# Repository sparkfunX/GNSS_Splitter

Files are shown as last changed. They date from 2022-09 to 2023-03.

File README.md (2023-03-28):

# SparkX GNSS Antenna Splitter (Power Divider) with DC Pass

<p align="center">
  <a href="https://github.com/sparkfunX/GNSS_Splitter/issues" alt="Issues">
    </a>
  <a href="https://github.com/sparkfunX/GNSS_Splitter/actions" alt="Actions">
    </a>
  <a href="https://github.com/sparkfunX/GNSS_Splitter/blob/main/LICENSE.md" alt="License">
    </a>
  <a href="https://twitter.com/intent/follow?screen_name=sparkfun">
    </a>
</p>

SparkX GNSS Antenna Splitter (Power Divider) with DC Pass (https://www.sparkfun.com/products/21223)

*[SparkX GNSS Antenna Splitter (Power Divider) with DC Pass (SPX-21223)](https://www.sparkfun.com/products/21223)*

The [SparkX GNSS Antenna Splitter (Power Divider) with DC Pass (SPX-21223)](https://www.sparkfun.com/products/21223) lets you connect a single GNSS antenna to two boards or modules. It splits (divides) the antenna signal from Port S equally between Port 1 and Port 2. It is the perfect accessory for our [NEO-D9S correction data receiver](https://www.sparkfun.com/products/19390), allowing you to feed both the NEO-D9S and a separate GNSS module from a single antenna.

Our board is based on the BP2G1+ 2-way 50Ω DC Pass Power Splitter from Mini-Circuits. It covers the L-band frequencies from 1200 to 2000 MHz. The three ports are equipped with robust standard-polarity SMA sockets. We have an SMA Male-Male adapter available as an accessory should you want to change any or all sockets into plugs.

By default, the splitter will pass DC power from Port 1 to the antenna (Port S) so you can power your active antenna. However, it is easy to change this if required:

* By opening Jumper 1 and closing Jumper 2, you can provide DC power from Port 2 instead.
* With Jumper 1 open, you can also provide DC power from either the on-board Qwiic connector or via the VCC and GND breakout pads.
* With Jumper 1 open and both Qwiic and VCC disconnected, you can use our board as a passive 50:50 signal divider or combiner.

If your antenna needs 3.3V, Qwiic could be a good choice for you. The VCC and GND breakout pads will allow you to feed in a higher voltage (e.g. 5V) if required.

We have included a 10Ω current-limiting resistor for the Qwiic and VCC power connections, to help prevent damage if the antenna cable becomes shorted. If your antenna needs more than approx. 30mA, you can close the I<sub>lim</sub> jumper to bypass the resistor.

## Repository Contents

* **[/Documents](/Documents/)** - BP2G1+ datasheet
* **[/Hardware](/Hardware/)** - Eagle design files (.brd, .sch), Schematic, Board Dimensions

## Product Versions

* [SPX-21223](https://www.sparkfun.com/products/21223) - SparkX GNSS Antenna Splitter (Power Divider) with DC Pass - Initial SparkX Release

## License Information

This product is _**open source**_! 

Please review the LICENSE.md file for license information. 

If you have any questions or concerns on licensing, please contact technical support on our [SparkFun forums](https://forum.sparkfun.com/viewforum.php?f=152).

Distributed as-is; no warranty is given.

- Your friends at SparkFun.

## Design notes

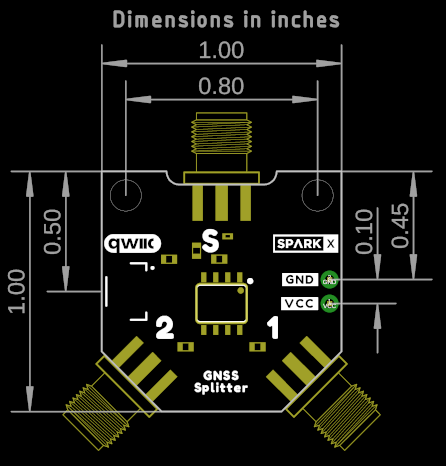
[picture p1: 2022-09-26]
Hardware/Dimensions.png

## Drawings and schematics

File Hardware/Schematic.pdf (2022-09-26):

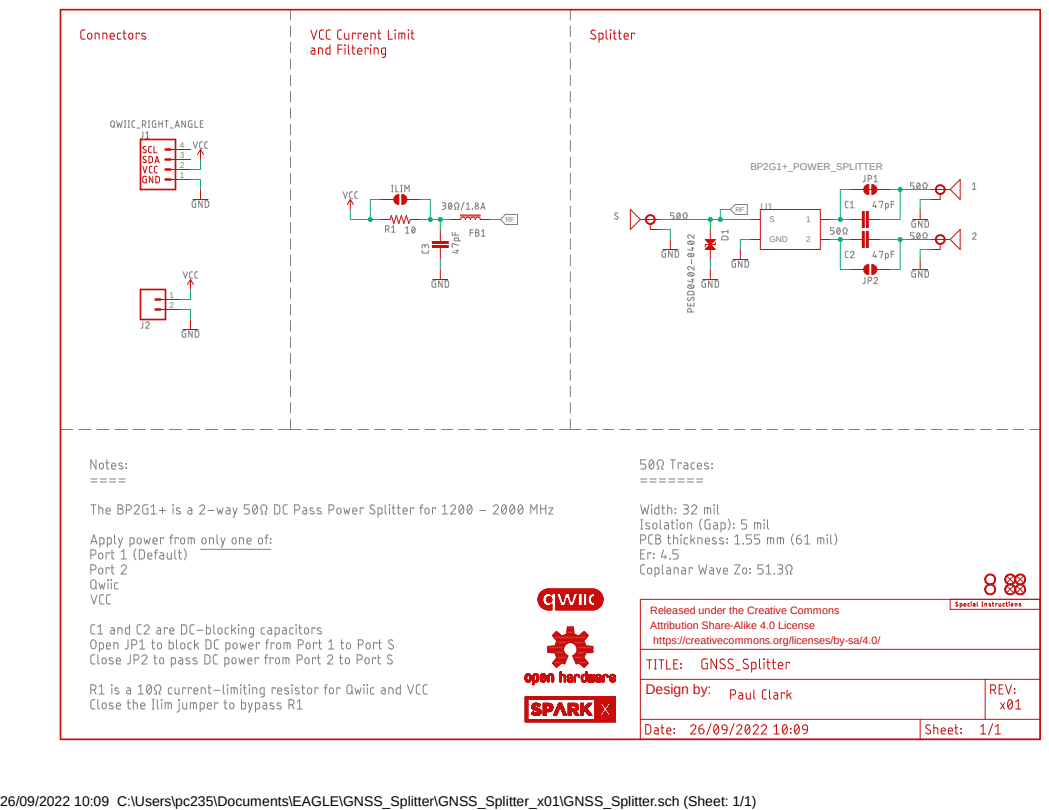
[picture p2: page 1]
BP2G1+_POWER_SPLITTER; 1 GND; Design by:

Released under the Creative Commons
Attribution Share-Alike 4.0 License
https://creativecommons.org/licenses/by-sa/4.0/

26/09/2022 10:09 C:\Users\pc235\Documents\EAGLE\GNSS_Splitter\GNSS_Splitter_x01\GNSS_Splitter.sch (Sheet: 1/1)

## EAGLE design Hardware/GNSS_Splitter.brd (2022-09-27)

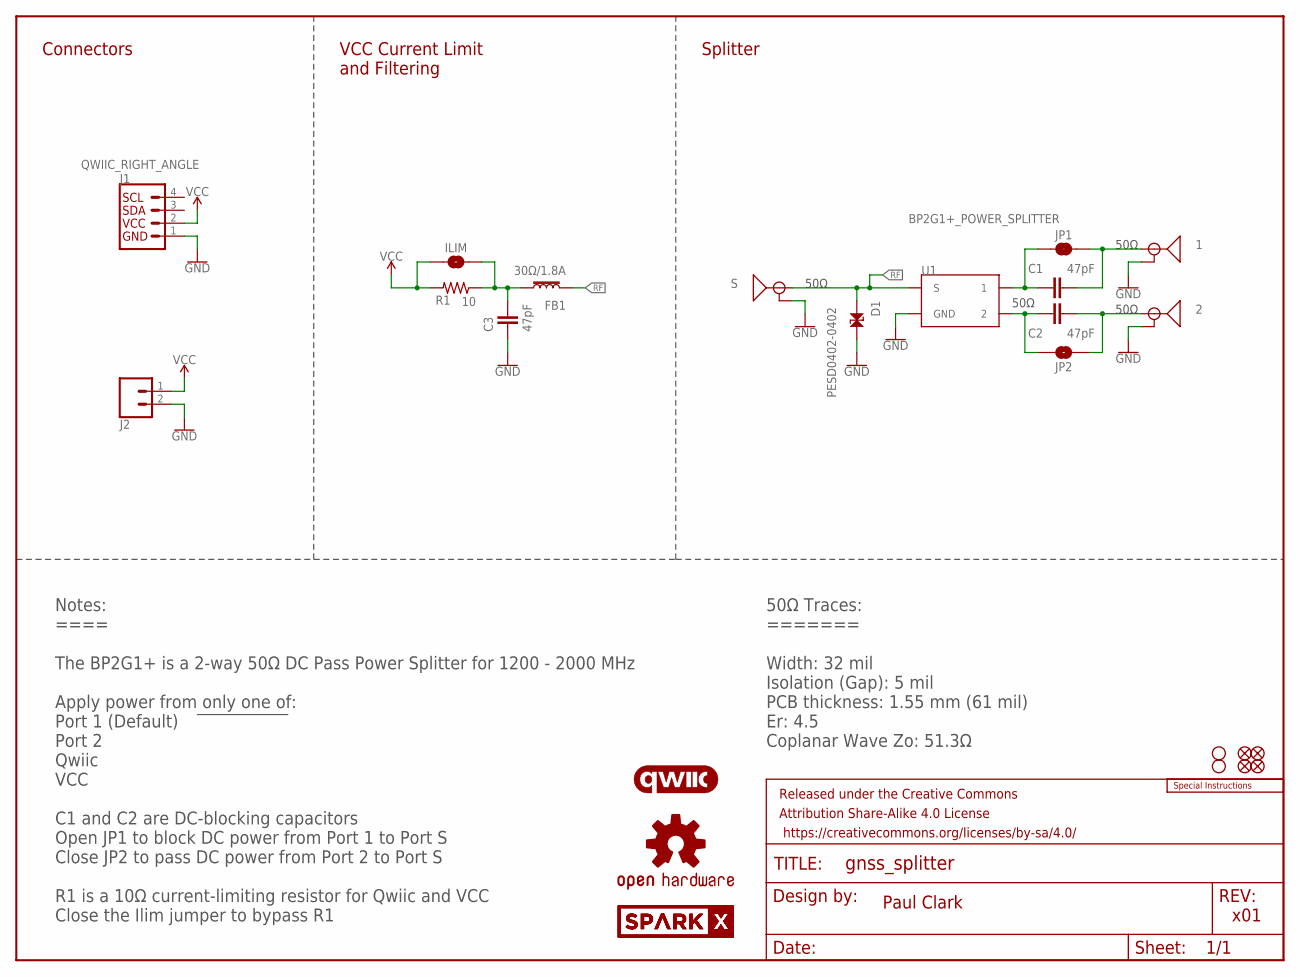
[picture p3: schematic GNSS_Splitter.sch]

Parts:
1, 2: ANTENNA-SMA-GROUNDEDEDGE_SMA; SMA-EDGE
C1, C2, C3: 47pF; 0603
D1: PESD0402-0402; 0402
FB1: 30Ω/1.8A; 0603
FD1, FD2, FD3, FD4: FIDUCIAL1X2; FIDUCIAL-1X2
FRAME1: FRAME-LETTER; CREATIVE_COMMONS
H1, H2: STAND-OFF
ILIM: JUMPER-SMT_2_NO_SILK; SMT-JUMPER_2_NO_SILK
J1: QWIIC_RIGHT_ANGLE; JST04_1MM_RA
J2: CONN_021X02_NO_SILK; 1X02_NO_SILK
JP1: JUMPER-SMT_2_NC_TRACE_SILK; SMT-JUMPER_2_NC_TRACE_SILK
JP2: JUMPER-SMT_2_NO_SILK; SMT-JUMPER_2_NO_SILK
LOGO1: OSHW-LOGOS; OSHW-LOGO-S
LOGO2: QWIIC_LOGO_6MM; QWIIC_6MM
LOGO3: SPECIAL_INSTRUCTIONS-ORDERING; ORDERING_INSTRUCTIONS
R1: 10; 0603
S: ANTENNA-SMA-GROUNDEDEDGE_SMA; SMA-EDGE
U1: BP2G1+_POWER_SPLITTER; XX21
U$1, U$2: SPARKX-LOGO3; SPARKX-SMALL

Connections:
GND: 1.GND@0 (GND), 1.GND@1 (GND), 1.GND@2 (GND), 1.GND@3 (GND), 2.GND@0 (GND), 2.GND@1 (GND), 2.GND@2 (GND), 2.GND@3 (GND), C3.1, D1.2, J1.1, J2.2, S.GND@0 (GND), S.GND@1 (GND), S.GND@2 (GND), S.GND@3 (GND), U1.1 (GND), U1.3 (GND), U1.4 (GND), U1.6 (GND), U1.7 (GND)
unnamed: C1.1, JP1.1, U1.8 (1)
unnamed: C3.2, FB1.1, ILIM.2, R1.1
unnamed: C2.2, JP2.2, U1.5 (2)
unnamed: 2.SIG (SIGNAL), C2.1, JP2.1
unnamed: 1.SIG (SIGNAL), C1.2, JP1.2
RF: D1.1, FB1.2, S.SIG (SIGNAL), U1.2 (S)
VCC: ILIM.1, J1.2, J2.1, R1.2

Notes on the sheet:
Paul Clark
x01
Notes: ==== The BP2G1+ is a 2-way 50Ω DC Pass Power Splitter for 1200 - 2000 MHz Apply power from only one of: Port 1 (Default) Port 2 Qwiic VCC C1 and C2 are DC-blocking capacitors Open JP1 to block DC power from Port 1 to Port S Close JP2 to pass DC power from Port 2 to Port S R1 is a 10Ω current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
50Ω
50Ω Traces: ======= Width: 32 mil Isolation (Gap): 5 mil PCB thickness: 1.55 mm (61 mil) Er: 4.5 Coplanar Wave Zo: 51.3Ω
Connectors
VCC Current Limit and Filtering
Splitter

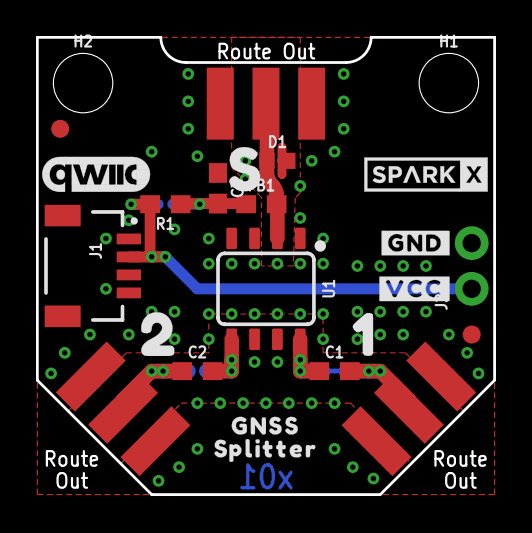
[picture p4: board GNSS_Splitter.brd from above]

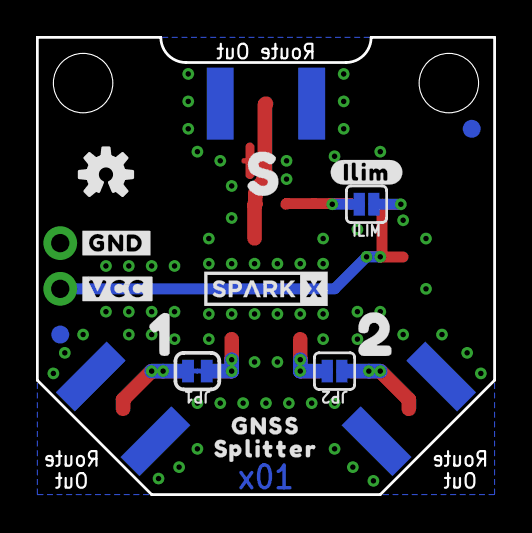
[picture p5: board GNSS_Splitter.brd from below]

Board: 2 copper layers, 25.4 x 25.4 mm, 44 parts (16 on the bottom side), 8 nets.

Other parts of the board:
U$3, U$7: 10
U$4, U$8: 20
U$5, U$6: S0
U$9: #GND#0
U$10: #GND#1
U$11: #VCC#0
U$12: #VCC#1
U$13, U$16: GNSS0
U$14, U$18: P0
U$15, U$17: S__LITTER0
U$19: #ILIM#0

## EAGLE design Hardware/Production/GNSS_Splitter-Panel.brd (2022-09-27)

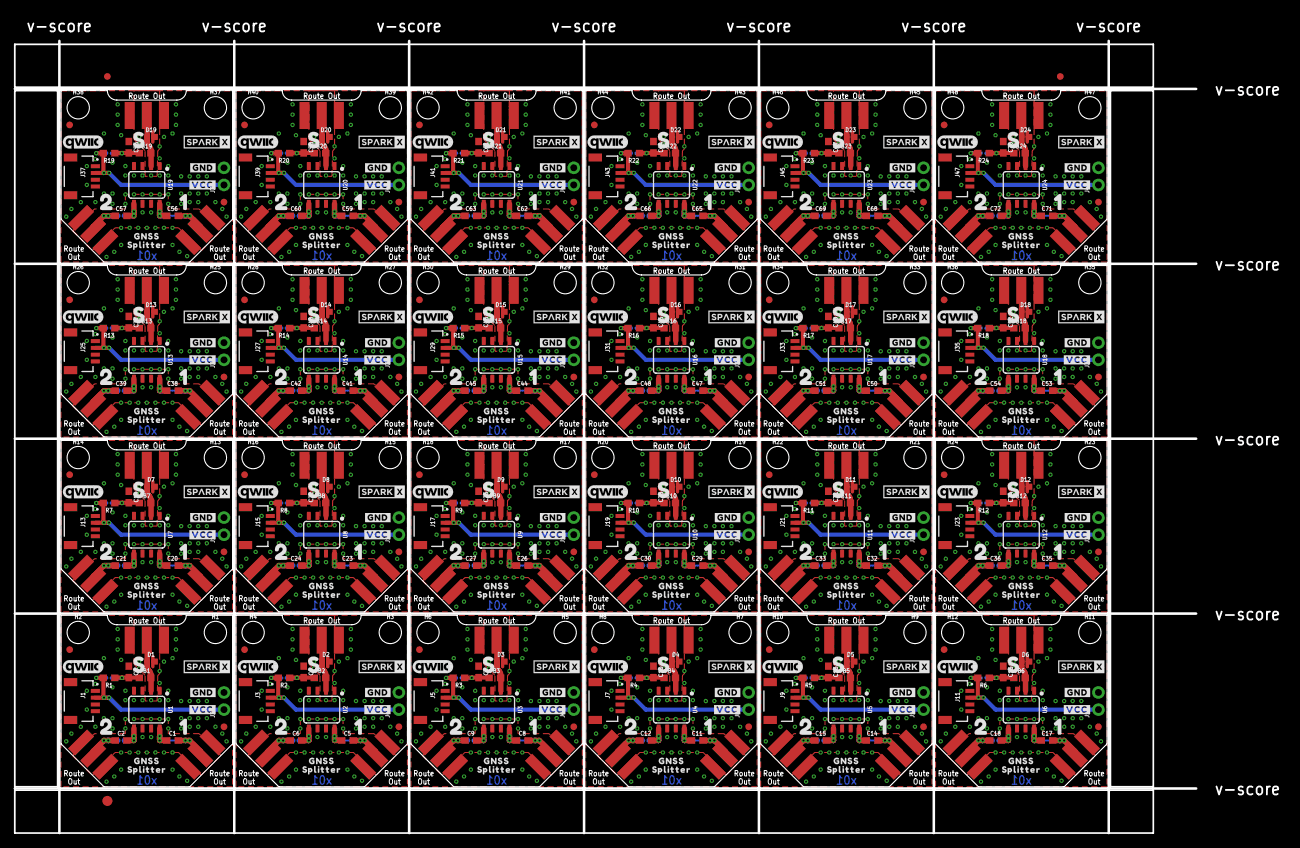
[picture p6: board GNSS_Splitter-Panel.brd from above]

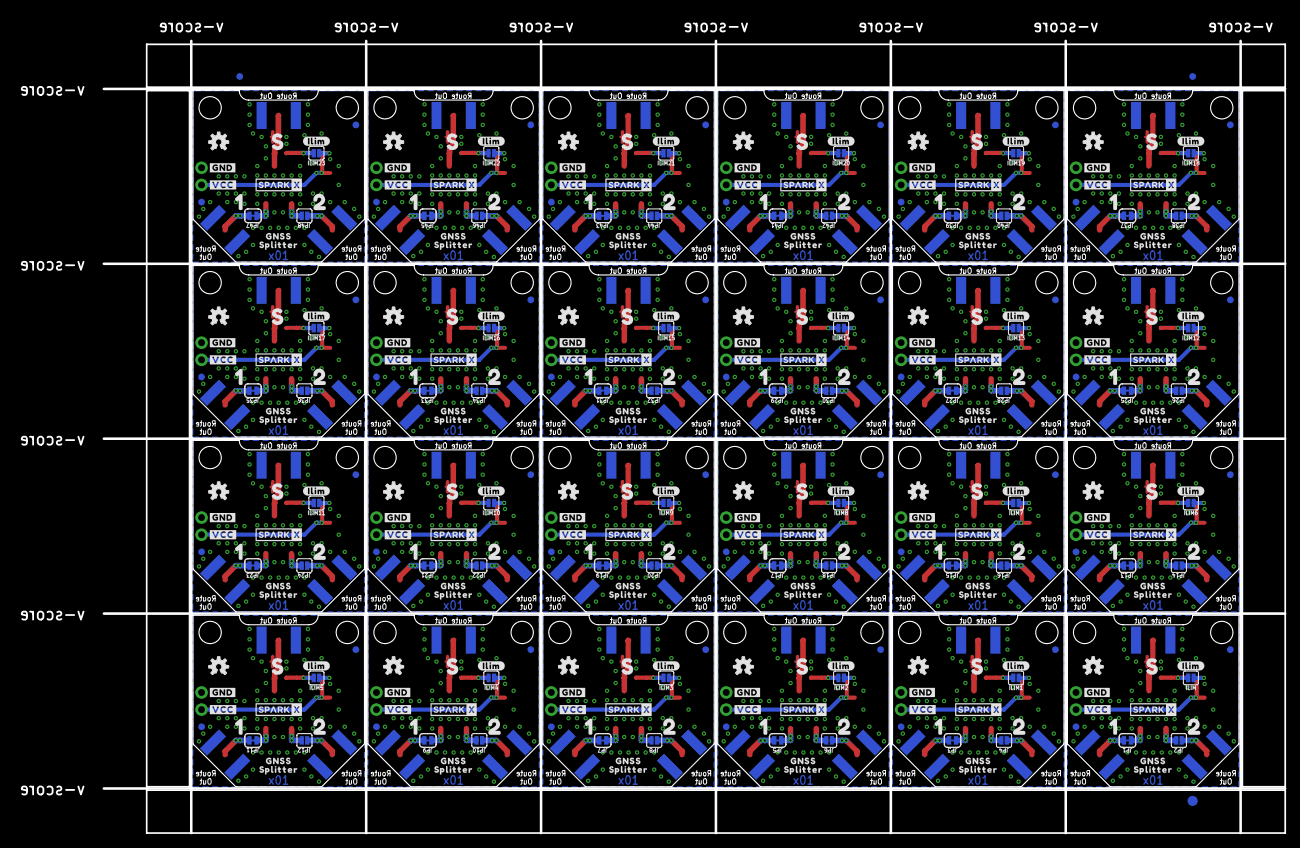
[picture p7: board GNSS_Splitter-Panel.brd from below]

Board: 2 copper layers, 175.0 x 117.3 mm, 1014 parts (387 on the bottom side), 192 nets.

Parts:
1, 2, 3, 4, 5, 6, 7, 8, 9, 10, 11, 12, 13, 14, 15, 16, 17, 18, 19, 20, 21, 22, 23, 24, 25, 26, 27, 28, 29, 30, 31, 32, 33, 34, 35, 36, 37, 38, 39, 40, 41, 42, 43, 44, 45, 46, 47, 48: ANTENNA-SMA-GROUNDEDEDGE_SMA; SMA-EDGE
C1, C2, C3, C4, C5, C6, C7, C8, C9, C10, C11, C12, C13, C14, C15, C16, C17, C18, C19, C20, C21, C22, C23, C24, C25, C26, C27, C28, C29, C30, C31, C32, C33, C34, C35, C36, C37, C38, C39, C40, C41, C42, C43, C44, C45, C46, C47, C48, C49, C50, C51, C52, C53, C54, C55, C56, C57, C58, C59, C60, C61, C62, C63, C64, C65, C66, C67, C68, C69, C70, C71, C72: 47pF; 0603
D1, D2, D3, D4, D5, D6, D7, D8, D9, D10, D11, D12, D13, D14, D15, D16, D17, D18, D19, D20, D21, D22, D23, D24: PESD0402-0402; 0402
E$1, E$2, E$3, E$4: FIDUCIAL-1X2
E$5, E$6: FIDUCIAL-1.5X3
FB1, FB2, FB3, FB4, FB5, FB6, FB7, FB8, FB9, FB10, FB11, FB12, FB13, FB14, FB15, FB16, FB17, FB18, FB19, FB20, FB21, FB22, FB23, FB24: 30Ω/1.8A; 0603
FD1, FD2, FD3, FD4, FD5, FD6, FD7, FD8, FD9, FD10, FD11, FD12, FD13, FD14, FD15, FD16, FD17, FD18, FD19, FD20, FD21, FD22, FD23, FD24, FD25, FD26, FD27, FD28, FD29, FD30, FD31, FD32, FD33, FD34, FD35, FD36, FD37, FD38, FD39, FD40, FD41, FD42, FD43, FD44, FD45, FD46, FD47, FD48, FD49, FD50, FD51, FD52, FD53, FD54, FD55, FD56, FD57, FD58, FD59, FD60, FD61, FD62, FD63, FD64, FD65, FD66, FD67, FD68, FD69, FD70, FD71, FD72, FD73, FD74, FD75, FD76, FD77, FD78, FD79, FD80, FD81, FD82, FD83, FD84, FD85, FD86, FD87, FD88, FD89, FD90, FD91, FD92, FD93, FD94, FD95, FD96: FIDUCIAL1X2; FIDUCIAL-1X2
H1, H2, H3, H4, H5, H6, H7, H8, H9, H10, H11, H12, H13, H14, H15, H16, H17, H18, H19, H20, H21, H22, H23, H24, H25, H26, H27, H28, H29, H30, H31, H32, H33, H34, H35, H36, H37, H38, H39, H40, H41, H42, H43, H44, H45, H46, H47, H48: STAND-OFF
ILIM, ILIM1, ILIM2, ILIM3, ILIM4, ILIM5, ILIM6, ILIM7, ILIM8, ILIM9, ILIM10, ILIM11, ILIM12, ILIM13, ILIM14, ILIM15, ILIM16, ILIM17, ILIM18, ILIM19, ILIM20, ILIM21, ILIM22, ILIM23: JUMPER-SMT_2_NO_SILK; SMT-JUMPER_2_NO_SILK
J1, J3, J5, J7, J9, J11, J13, J15, J17, J19, J21, J23, J25, J27, J29, J31, J33, J35, J37, J39, J41, J43, J45, J47: QWIIC_RIGHT_ANGLE; JST04_1MM_RA
J2, J4, J6, J8, J10, J12, J14, J16, J18, J20, J22, J24, J26, J28, J30, J32, J34, J36, J38, J40, J42, J44, J46, J48: 1X02_NO_SILK
JP1, JP3, JP5, JP7, JP9, JP11, JP13, JP15, JP17, JP19, JP21, JP23, JP25, JP27, JP29, JP31, JP33, JP35, JP37, JP39, JP41, JP43, JP45, JP47: JUMPER-SMT_2_NC_TRACE_SILK; SMT-JUMPER_2_NC_TRACE_SILK
JP2, JP4, JP6, JP8, JP10, JP12, JP14, JP16, JP18, JP20, JP22, JP24, JP26, JP28, JP30, JP32, JP34, JP36, JP38, JP40, JP42, JP44, JP46, JP48: JUMPER-SMT_2_NO_SILK; SMT-JUMPER_2_NO_SILK
LOGO1, LOGO3, LOGO5, LOGO7, LOGO9, LOGO11, LOGO13, LOGO15, LOGO17, LOGO19, LOGO21, LOGO23, LOGO25, LOGO27, LOGO29, LOGO31, LOGO33, LOGO35, LOGO37, LOGO39, LOGO41, LOGO43, LOGO45, LOGO47: OSHW-LOGOS; OSHW-LOGO-S
LOGO2, LOGO4, LOGO6, LOGO8, LOGO10, LOGO12, LOGO14, LOGO16, LOGO18, LOGO20, LOGO22, LOGO24, LOGO26, LOGO28, LOGO30, LOGO32, LOGO34, LOGO36, LOGO38, LOGO40, LOGO42, LOGO44, LOGO46, LOGO48: QWIIC_LOGO_6MM; QWIIC_6MM
R1, R2, R3, R4, R5, R6, R7, R8, R9, R10, R11, R12, R13, R14, R15, R16, R17, R18, R19, R20, R21, R22, R23, R24: 10; 0603
S, S1, S2, S3, S4, S5, S6, S7, S8, S9, S10, S11, S12, S13, S14, S15, S16, S17, S18, S19, S20, S21, S22, S23: ANTENNA-SMA-GROUNDEDEDGE_SMA; SMA-EDGE
U1, U2, U3, U4, U5, U6, U7, U8, U9, U10, U11, U12, U13, U14, U15, U16, U17, U18, U19, U20, U21, U22, U23, U24: BP2G1+_POWER_SPLITTER; XX21
U$1, U$2, U$20, U$21, U$39, U$40, U$58, U$59, U$77, U$78, U$96, U$97, U$115, U$116, U$134, U$135, U$153, U$154, U$172, U$173, U$191, U$192, U$210, U$211, U$229, U$230, U$248, U$249, U$267, U$268, U$286, U$287, U$305, U$306, U$324, U$325, U$343, U$344, U$362, U$363, U$381, U$382, U$400, U$401, U$419, U$420, U$438, U$439: SPARKX-LOGO3; SPARKX-SMALL
U$3, U$7, U$22, U$26, U$41, U$45, U$60, U$64, U$79, U$83, U$98, U$102, U$117, U$121, U$136, U$140, U$155, U$159, U$174, U$178, U$193, U$197, U$212, U$216, U$231, U$235, U$250, U$254, U$269, U$273, U$288, U$292, U$307, U$311, U$326, U$330, U$345, U$349, U$364, U$368, U$383, U$387, U$402, U$406, U$421, U$425, U$440, U$444: 10
U$4, U$8, U$23, U$27, U$42, U$46, U$61, U$65, U$80, U$84, U$99, U$103, U$118, U$122, U$137, U$141, U$156, U$160, U$175, U$179, U$194, U$198, U$213, U$217, U$232, U$236, U$251, U$255, U$270, U$274, U$289, U$293, U$308, U$312, U$327, U$331, U$346, U$350, U$365, U$369, U$384, U$388, U$403, U$407, U$422, U$426, U$441, U$445: 20
U$5, U$6, U$24, U$25, U$43, U$44, U$62, U$63, U$81, U$82, U$100, U$101, U$119, U$120, U$138, U$139, U$157, U$158, U$176, U$177, U$195, U$196, U$214, U$215, U$233, U$234, U$252, U$253, U$271, U$272, U$290, U$291, U$309, U$310, U$328, U$329, U$347, U$348, U$366, U$367, U$385, U$386, U$404, U$405, U$423, U$424, U$442, U$443: S0
U$9, U$28, U$47, U$66, U$85, U$104, U$123, U$142, U$161, U$180, U$199, U$218, U$237, U$256, U$275, U$294, U$313, U$332, U$351, U$370, U$389, U$408, U$427, U$446: #GND#0
U$10, U$29, U$48, U$67, U$86, U$105, U$124, U$143, U$162, U$181, U$200, U$219, U$238, U$257, U$276, U$295, U$314, U$333, U$352, U$371, U$390, U$409, U$428, U$447: #GND#1
U$11, U$37, U$56, U$75, U$94, U$113, U$132, U$151, U$170, U$189, U$208, U$227, U$246, U$265, U$284, U$303, U$322, U$341, U$360, U$379, U$398, U$417, U$436, U$455: #VCC#0
U$12, U$38, U$57, U$76, U$95, U$114, U$133, U$152, U$171, U$190, U$209, U$228, U$247, U$266, U$285, U$304, U$323, U$342, U$361, U$380, U$399, U$418, U$437, U$456: #VCC#1
U$13, U$16, U$30, U$33, U$49, U$52, U$68, U$71, U$87, U$90, U$106, U$109, U$125, U$128, U$144, U$147, U$163, U$166, U$182, U$185, U$201, U$204, U$220, U$223, U$239, U$242, U$258, U$261, U$277, U$280, U$296, U$299, U$315, U$318, U$334, U$337, U$353, U$356, U$372, U$375, U$391, U$394, U$410, U$413, U$429, U$432, U$448, U$451: GNSS0
U$14, U$18, U$32, U$35, U$51, U$54, U$70, U$73, U$89, U$92, U$108, U$111, U$127, U$130, U$146, U$149, U$165, U$168, U$184, U$187, U$203, U$206, U$222, U$225, U$241, U$244, U$260, U$263, U$279, U$282, U$298, U$301, U$317, U$320, U$336, U$339, U$355, U$358, U$374, U$377, U$393, U$396, U$412, U$415, U$431, U$434, U$450, U$453: P0
U$15, U$17, U$31, U$34, U$50, U$53, U$69, U$72, U$88, U$91, U$107, U$110, U$126, U$129, U$145, U$148, U$164, U$167, U$183, U$186, U$202, U$205, U$221, U$224, U$240, U$243, U$259, U$262, U$278, U$281, U$297, U$300, U$316, U$319, U$335, U$338, U$354, U$357, U$373, U$376, U$392, U$395, U$411, U$414, U$430, U$433, U$449, U$452: S__LITTER0
U$19, U$36, U$55, U$74, U$93, U$112, U$131, U$150, U$169, U$188, U$207, U$226, U$245, U$264, U$283, U$302, U$321, U$340, U$359, U$378, U$397, U$416, U$435, U$454: #ILIM#0

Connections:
GND: 1.GND@0, 1.GND@1, 1.GND@2, 1.GND@3, 2.GND@0, 2.GND@1, 2.GND@2, 2.GND@3, C3.1, D1.2, J1.1, J2.2, S.GND@0, S.GND@1, S.GND@2, S.GND@3, U1.1, U1.3, U1.4, U1.6, U1.7
GND1: 3.GND@0, 3.GND@1, 3.GND@2, 3.GND@3, 4.GND@0, 4.GND@1, 4.GND@2, 4.GND@3, C4.1, D2.2, J3.1, J4.2, S1.GND@0, S1.GND@1, S1.GND@2, S1.GND@3, U2.1, U2.3, U2.4, U2.6, U2.7
GND2: 5.GND@0, 5.GND@1, 5.GND@2, 5.GND@3, 6.GND@0, 6.GND@1, 6.GND@2, 6.GND@3, C7.1, D3.2, J5.1, J6.2, S2.GND@0, S2.GND@1, S2.GND@2, S2.GND@3, U3.1, U3.3, U3.4, U3.6, U3.7
GND3: 7.GND@0, 7.GND@1, 7.GND@2, 7.GND@3, 8.GND@0, 8.GND@1, 8.GND@2, 8.GND@3, C10.1, D4.2, J7.1, J8.2, S3.GND@0, S3.GND@1, S3.GND@2, S3.GND@3, U4.1, U4.3, U4.4, U4.6, U4.7
GND4: 9.GND@0, 9.GND@1, 9.GND@2, 9.GND@3, 10.GND@0, 10.GND@1, 10.GND@2, 10.GND@3, C13.1, D5.2, J9.1, J10.2, S4.GND@0, S4.GND@1, S4.GND@2, S4.GND@3, U5.1, U5.3, U5.4, U5.6, U5.7
GND5: 11.GND@0, 11.GND@1, 11.GND@2, 11.GND@3, 12.GND@0, 12.GND@1, 12.GND@2, 12.GND@3, C16.1, D6.2, J11.1, J12.2, S5.GND@0, S5.GND@1, S5.GND@2, S5.GND@3, U6.1, U6.3, U6.4, U6.6, U6.7
GND6: 13.GND@0, 13.GND@1, 13.GND@2, 13.GND@3, 14.GND@0, 14.GND@1, 14.GND@2, 14.GND@3, C19.1, D7.2, J13.1, J14.2, S6.GND@0, S6.GND@1, S6.GND@2, S6.GND@3, U7.1, U7.3, U7.4, U7.6, U7.7
GND7: 15.GND@0, 15.GND@1, 15.GND@2, 15.GND@3, 16.GND@0, 16.GND@1, 16.GND@2, 16.GND@3, C22.1, D8.2, J15.1, J16.2, S7.GND@0, S7.GND@1, S7.GND@2, S7.GND@3, U8.1, U8.3, U8.4, U8.6, U8.7
GND8: 17.GND@0, 17.GND@1, 17.GND@2, 17.GND@3, 18.GND@0, 18.GND@1, 18.GND@2, 18.GND@3, C25.1, D9.2, J17.1, J18.2, S8.GND@0, S8.GND@1, S8.GND@2, S8.GND@3, U9.1, U9.3, U9.4, U9.6, U9.7
GND9: 19.GND@0, 19.GND@1, 19.GND@2, 19.GND@3, 20.GND@0, 20.GND@1, 20.GND@2, 20.GND@3, C28.1, D10.2, J19.1, J20.2, S9.GND@0, S9.GND@1, S9.GND@2, S9.GND@3, U10.1, U10.3, U10.4, U10.6, U10.7
GND10: 21.GND@0, 21.GND@1, 21.GND@2, 21.GND@3, 22.GND@0, 22.GND@1, 22.GND@2, 22.GND@3, C31.1, D11.2, J21.1, J22.2, S10.GND@0, S10.GND@1, S10.GND@2, S10.GND@3, U11.1, U11.3, U11.4, U11.6, U11.7
GND11: 23.GND@0, 23.GND@1, 23.GND@2, 23.GND@3, 24.GND@0, 24.GND@1, 24.GND@2, 24.GND@3, C34.1, D12.2, J23.1, J24.2, S11.GND@0, S11.GND@1, S11.GND@2, S11.GND@3, U12.1, U12.3, U12.4, U12.6, U12.7
GND12: 25.GND@0, 25.GND@1, 25.GND@2, 25.GND@3, 26.GND@0, 26.GND@1, 26.GND@2, 26.GND@3, C37.1, D13.2, J25.1, J26.2, S12.GND@0, S12.GND@1, S12.GND@2, S12.GND@3, U13.1, U13.3, U13.4, U13.6, U13.7
GND13: 27.GND@0, 27.GND@1, 27.GND@2, 27.GND@3, 28.GND@0, 28.GND@1, 28.GND@2, 28.GND@3, C40.1, D14.2, J27.1, J28.2, S13.GND@0, S13.GND@1, S13.GND@2, S13.GND@3, U14.1, U14.3, U14.4, U14.6, U14.7
GND14: 29.GND@0, 29.GND@1, 29.GND@2, 29.GND@3, 30.GND@0, 30.GND@1, 30.GND@2, 30.GND@3, C43.1, D15.2, J29.1, J30.2, S14.GND@0, S14.GND@1, S14.GND@2, S14.GND@3, U15.1, U15.3, U15.4, U15.6, U15.7
GND15: 31.GND@0, 31.GND@1, 31.GND@2, 31.GND@3, 32.GND@0, 32.GND@1, 32.GND@2, 32.GND@3, C46.1, D16.2, J31.1, J32.2, S15.GND@0, S15.GND@1, S15.GND@2, S15.GND@3, U16.1, U16.3, U16.4, U16.6, U16.7
GND16: 33.GND@0, 33.GND@1, 33.GND@2, 33.GND@3, 34.GND@0, 34.GND@1, 34.GND@2, 34.GND@3, C49.1, D17.2, J33.1, J34.2, S16.GND@0, S16.GND@1, S16.GND@2, S16.GND@3, U17.1, U17.3, U17.4, U17.6, U17.7
GND17: 35.GND@0, 35.GND@1, 35.GND@2, 35.GND@3, 36.GND@0, 36.GND@1, 36.GND@2, 36.GND@3, C52.1, D18.2, J35.1, J36.2, S17.GND@0, S17.GND@1, S17.GND@2, S17.GND@3, U18.1, U18.3, U18.4, U18.6, U18.7
GND18: 37.GND@0, 37.GND@1, 37.GND@2, 37.GND@3, 38.GND@0, 38.GND@1, 38.GND@2, 38.GND@3, C55.1, D19.2, J37.1, J38.2, S18.GND@0, S18.GND@1, S18.GND@2, S18.GND@3, U19.1, U19.3, U19.4, U19.6, U19.7
GND19: 39.GND@0, 39.GND@1, 39.GND@2, 39.GND@3, 40.GND@0, 40.GND@1, 40.GND@2, 40.GND@3, C58.1, D20.2, J39.1, J40.2, S19.GND@0, S19.GND@1, S19.GND@2, S19.GND@3, U20.1, U20.3, U20.4, U20.6, U20.7
GND20: 41.GND@0, 41.GND@1, 41.GND@2, 41.GND@3, 42.GND@0, 42.GND@1, 42.GND@2, 42.GND@3, C61.1, D21.2, J41.1, J42.2, S20.GND@0, S20.GND@1, S20.GND@2, S20.GND@3, U21.1, U21.3, U21.4, U21.6, U21.7
GND21: 43.GND@0, 43.GND@1, 43.GND@2, 43.GND@3, 44.GND@0, 44.GND@1, 44.GND@2, 44.GND@3, C64.1, D22.2, J43.1, J44.2, S21.GND@0, S21.GND@1, S21.GND@2, S21.GND@3, U22.1, U22.3, U22.4, U22.6, U22.7
GND22: 45.GND@0, 45.GND@1, 45.GND@2, 45.GND@3, 46.GND@0, 46.GND@1, 46.GND@2, 46.GND@3, C67.1, D23.2, J45.1, J46.2, S22.GND@0, S22.GND@1, S22.GND@2, S22.GND@3, U23.1, U23.3, U23.4, U23.6, U23.7
GND23: 47.GND@0, 47.GND@1, 47.GND@2, 47.GND@3, 48.GND@0, 48.GND@1, 48.GND@2, 48.GND@3, C70.1, D24.2, J47.1, J48.2, S23.GND@0, S23.GND@1, S23.GND@2, S23.GND@3, U24.1, U24.3, U24.4, U24.6, U24.7
unnamed: C1.1, JP1.1, U1.8
unnamed: C3.2, FB1.1, ILIM.2, R1.1
unnamed: C2.2, JP2.2, U1.5
unnamed: C5.1, JP3.1, U2.8
unnamed: 2.SIG, C2.1, JP2.1
unnamed: 1.SIG, C1.2, JP1.2
unnamed: C6.2, JP4.2, U2.5
unnamed: 3.SIG, C6.1, JP4.1
unnamed: 4.SIG, C5.2, JP3.2
unnamed: C4.2, FB2.1, ILIM1.2, R2.1
unnamed: C8.1, JP5.1, U3.8
unnamed: C9.2, JP6.2, U3.5
unnamed: 5.SIG, C9.1, JP6.1
unnamed: 6.SIG, C8.2, JP5.2
unnamed: C7.2, FB3.1, ILIM2.2, R3.1
unnamed: C11.1, JP7.1, U4.8
unnamed: C12.2, JP8.2, U4.5
unnamed: 7.SIG, C12.1, JP8.1
unnamed: 8.SIG, C11.2, JP7.2
unnamed: C10.2, FB4.1, ILIM3.2, R4.1
unnamed: C14.1, JP9.1, U5.8
unnamed: C15.2, JP10.2, U5.5
unnamed: 9.SIG, C15.1, JP10.1
unnamed: 10.SIG, C14.2, JP9.2
unnamed: C13.2, FB5.1, ILIM4.2, R5.1
unnamed: C17.1, JP11.1, U6.8
unnamed: C18.2, JP12.2, U6.5
unnamed: 11.SIG, C18.1, JP12.1
unnamed: 12.SIG, C17.2, JP11.2
unnamed: C16.2, FB6.1, ILIM5.2, R6.1
unnamed: C20.1, JP13.1, U7.8
unnamed: C21.2, JP14.2, U7.5
unnamed: 13.SIG, C21.1, JP14.1
unnamed: 14.SIG, C20.2, JP13.2
unnamed: C19.2, FB7.1, ILIM6.2, R7.1
unnamed: C23.1, JP15.1, U8.8
unnamed: C24.2, JP16.2, U8.5
unnamed: 15.SIG, C24.1, JP16.1
unnamed: 16.SIG, C23.2, JP15.2
unnamed: C22.2, FB8.1, ILIM7.2, R8.1
unnamed: C26.1, JP17.1, U9.8
unnamed: C27.2, JP18.2, U9.5
unnamed: 17.SIG, C27.1, JP18.1
unnamed: 18.SIG, C26.2, JP17.2
unnamed: C25.2, FB9.1, ILIM8.2, R9.1
unnamed: C29.1, JP19.1, U10.8
unnamed: C30.2, JP20.2, U10.5
unnamed: 19.SIG, C30.1, JP20.1
unnamed: 20.SIG, C29.2, JP19.2
unnamed: C28.2, FB10.1, ILIM9.2, R10.1
unnamed: C32.1, JP21.1, U11.8
unnamed: C33.2, JP22.2, U11.5
unnamed: 21.SIG, C33.1, JP22.1
unnamed: 22.SIG, C32.2, JP21.2
unnamed: C31.2, FB11.1, ILIM10.2, R11.1
unnamed: C35.1, JP23.1, U12.8
unnamed: C36.2, JP24.2, U12.5
unnamed: 23.SIG, C36.1, JP24.1
unnamed: 24.SIG, C35.2, JP23.2
unnamed: C34.2, FB12.1, ILIM11.2, R12.1
unnamed: C38.1, JP25.1, U13.8
unnamed: C39.2, JP26.2, U13.5
unnamed: 25.SIG, C39.1, JP26.1
unnamed: 26.SIG, C38.2, JP25.2
unnamed: C37.2, FB13.1, ILIM12.2, R13.1
unnamed: C41.1, JP27.1, U14.8
unnamed: C42.2, JP28.2, U14.5
unnamed: 27.SIG, C42.1, JP28.1
unnamed: 28.SIG, C41.2, JP27.2
unnamed: C40.2, FB14.1, ILIM13.2, R14.1
unnamed: C44.1, JP29.1, U15.8
unnamed: C45.2, JP30.2, U15.5
unnamed: 29.SIG, C45.1, JP30.1
unnamed: 30.SIG, C44.2, JP29.2
unnamed: C43.2, FB15.1, ILIM14.2, R15.1
unnamed: C47.1, JP31.1, U16.8
unnamed: C48.2, JP32.2, U16.5
unnamed: 31.SIG, C48.1, JP32.1
unnamed: 32.SIG, C47.2, JP31.2
unnamed: C46.2, FB16.1, ILIM15.2, R16.1
unnamed: C50.1, JP33.1, U17.8
unnamed: C51.2, JP34.2, U17.5
unnamed: 33.SIG, C51.1, JP34.1
unnamed: 34.SIG, C50.2, JP33.2
unnamed: C49.2, FB17.1, ILIM16.2, R17.1
unnamed: C53.1, JP35.1, U18.8
unnamed: C54.2, JP36.2, U18.5
unnamed: 35.SIG, C54.1, JP36.1
unnamed: 36.SIG, C53.2, JP35.2
unnamed: C52.2, FB18.1, ILIM17.2, R18.1
unnamed: C56.1, JP37.1, U19.8
unnamed: C57.2, JP38.2, U19.5
unnamed: 37.SIG, C57.1, JP38.1
unnamed: 38.SIG, C56.2, JP37.2
unnamed: C55.2, FB19.1, ILIM18.2, R19.1
unnamed: C59.1, JP39.1, U20.8
unnamed: C60.2, JP40.2, U20.5
unnamed: 39.SIG, C60.1, JP40.1
unnamed: 40.SIG, C59.2, JP39.2
unnamed: C58.2, FB20.1, ILIM19.2, R20.1
unnamed: C62.1, JP41.1, U21.8
unnamed: C63.2, JP42.2, U21.5
unnamed: 41.SIG, C63.1, JP42.1
unnamed: 42.SIG, C62.2, JP41.2
unnamed: C61.2, FB21.1, ILIM20.2, R21.1
unnamed: C65.1, JP43.1, U22.8
unnamed: C66.2, JP44.2, U22.5
unnamed: 43.SIG, C66.1, JP44.1
unnamed: 44.SIG, C65.2, JP43.2
unnamed: C64.2, FB22.1, ILIM21.2, R22.1
unnamed: C68.1, JP45.1, U23.8
unnamed: C69.2, JP46.2, U23.5
unnamed: 45.SIG, C69.1, JP46.1
unnamed: 46.SIG, C68.2, JP45.2
unnamed: C67.2, FB23.1, ILIM22.2, R23.1
unnamed: C71.1, JP47.1, U24.8
unnamed: C72.2, JP48.2, U24.5
unnamed: 47.SIG, C72.1, JP48.1
unnamed: 48.SIG, C71.2, JP47.2
unnamed: C70.2, FB24.1, ILIM23.2, R24.1
RF: D1.1, FB1.2, S.SIG, U1.2
RF1: D2.1, FB2.2, S1.SIG, U2.2
RF2: D3.1, FB3.2, S2.SIG, U3.2
RF3: D4.1, FB4.2, S3.SIG, U4.2
RF4: D5.1, FB5.2, S4.SIG, U5.2
RF5: D6.1, FB6.2, S5.SIG, U6.2
RF6: D7.1, FB7.2, S6.SIG, U7.2
RF7: D8.1, FB8.2, S7.SIG, U8.2
RF8: D9.1, FB9.2, S8.SIG, U9.2
RF9: D10.1, FB10.2, S9.SIG, U10.2
RF10: D11.1, FB11.2, S10.SIG, U11.2
RF11: D12.1, FB12.2, S11.SIG, U12.2
RF12: D13.1, FB13.2, S12.SIG, U13.2
RF13: D14.1, FB14.2, S13.SIG, U14.2
RF14: D15.1, FB15.2, S14.SIG, U15.2
RF15: D16.1, FB16.2, S15.SIG, U16.2
RF16: D17.1, FB17.2, S16.SIG, U17.2
RF17: D18.1, FB18.2, S17.SIG, U18.2
RF18: D19.1, FB19.2, S18.SIG, U19.2
RF19: D20.1, FB20.2, S19.SIG, U20.2
RF20: D21.1, FB21.2, S20.SIG, U21.2
RF21: D22.1, FB22.2, S21.SIG, U22.2
RF22: D23.1, FB23.2, S22.SIG, U23.2
RF23: D24.1, FB24.2, S23.SIG, U24.2
VCC: ILIM.1, J1.2, J2.1, R1.2
VCC1: ILIM1.1, J3.2, J4.1, R2.2
VCC2: ILIM2.1, J5.2, J6.1, R3.2
VCC3: ILIM3.1, J7.2, J8.1, R4.2
VCC4: ILIM4.1, J9.2, J10.1, R5.2
VCC5: ILIM5.1, J11.2, J12.1, R6.2
VCC6: ILIM6.1, J13.2, J14.1, R7.2
VCC7: ILIM7.1, J15.2, J16.1, R8.2
VCC8: ILIM8.1, J17.2, J18.1, R9.2
VCC9: ILIM9.1, J19.2, J20.1, R10.2
VCC10: ILIM10.1, J21.2, J22.1, R11.2
VCC11: ILIM11.1, J23.2, J24.1, R12.2
VCC12: ILIM12.1, J25.2, J26.1, R13.2
VCC13: ILIM13.1, J27.2, J28.1, R14.2
VCC14: ILIM14.1, J29.2, J30.1, R15.2
VCC15: ILIM15.1, J31.2, J32.1, R16.2
VCC16: ILIM16.1, J33.2, J34.1, R17.2
VCC17: ILIM17.1, J35.2, J36.1, R18.2
VCC18: ILIM18.1, J37.2, J38.1, R19.2
VCC19: ILIM19.1, J39.2, J40.1, R20.2
VCC20: ILIM20.1, J41.2, J42.1, R21.2
VCC21: ILIM21.1, J43.2, J44.1, R22.2
VCC22: ILIM22.1, J45.2, J46.1, R23.2
VCC23: ILIM23.1, J47.2, J48.1, R24.2

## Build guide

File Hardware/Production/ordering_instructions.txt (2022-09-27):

panel size, 169x117mm
PCB thickness, 1.6mm
number of layers, 2
soldermask color, Black
silkscreen color, White
oz copper, 1oz
finish, HASL lead free
stencils, top
pcs per panel, 24
min trace width, 0.3048mm / 0.0120in
min drill size, 0.3000mm / 0.0118in

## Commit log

2022-09-26 Ready for review
    [GNSS_Splitter-Panel.GBL, GNSS_Splitter-Panel.GBO, GNSS_Splitter-Panel.GBP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]
2022-09-27 x01 PCB
    [GNSS_Splitter-Panel.brd, GNSS_Splitter.brd, GNSS_Splitter.sch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]

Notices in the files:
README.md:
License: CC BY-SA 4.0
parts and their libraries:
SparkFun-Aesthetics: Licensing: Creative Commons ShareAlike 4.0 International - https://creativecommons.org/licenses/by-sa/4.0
